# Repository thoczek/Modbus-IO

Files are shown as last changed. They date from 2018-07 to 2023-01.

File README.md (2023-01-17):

# Modbus-IO modules<br>

### Complete Modbus I/O modules on ATmega8<br>
### Contains:<br>
 - 4DI-4DO - 4 digital inputs 24VDC and 4 relay NO/NC outputs<br>
 - 8DI - 8 digital inputs 24VDC<br>
 - 7RO - 7 Relay outputs NO/NC<br>
 - WIFI - Module for WIFI conectibity for modules<br>
 - EAP-MODBUSconfig - Software for configuration of the modules.<br>
   Modules have possibility to act in TCP mode throught WIFi module.<br>

### Technology used:
Schematics and PCB board done in Kicad.<br>
Firmware - C++ eclipse. <br>
Software - C#

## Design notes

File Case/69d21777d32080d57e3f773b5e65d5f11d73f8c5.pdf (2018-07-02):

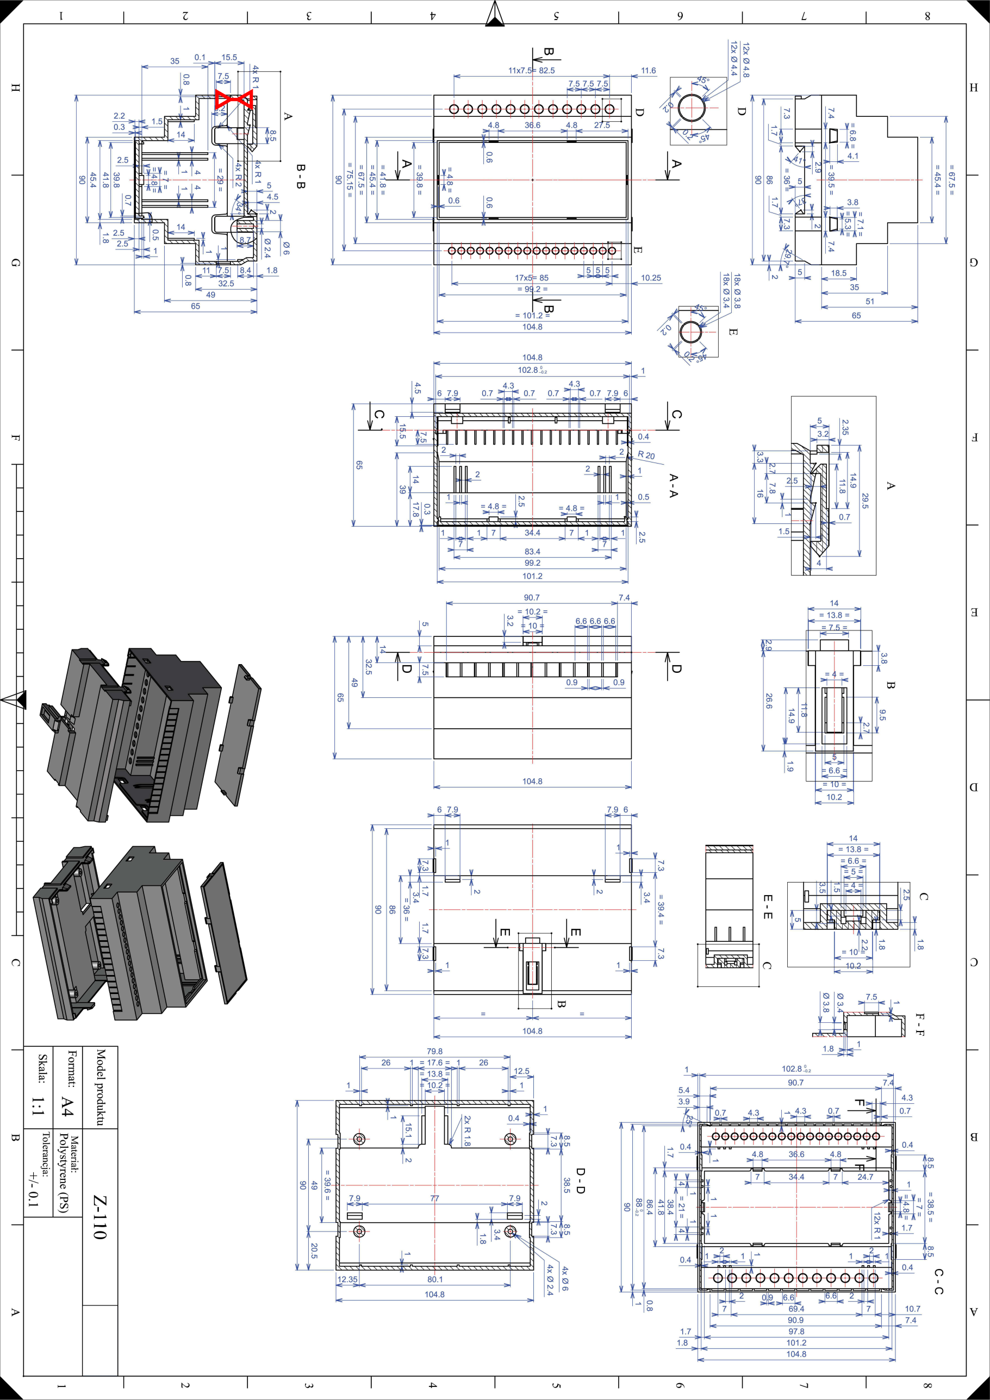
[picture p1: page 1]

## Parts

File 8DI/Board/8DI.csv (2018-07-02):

ref | value
C1 | 30pF
C2 | 30pF
C3 | 100nF
C4 | 47uF
C5 | 4,7uF
C6 | 47uF
C7 | 100nF
C8 | 100nF
C9 | 100nF
C10 | 100nF
C11 | 100nF
C12 | 100nF
C13 | 100nF
C14 | 100nF
C15 | 100nF
C16 | 4,7uF
C17 | 100nF
C18 | 100nF
C19 | 100nF
C20 | 100nF
D1 | DIODE
D2 | Tr 30V
D3 | LED
D4 | Tr 5.8V
D5 | Tr 5.8V
D6 | Tr 5.8V
D7 | Tr 5.8V
D8 | Tr 5.8V
D9 | Tr 5.8V
D10 | Tr 5.8V
D11 | Tr 5.8V
D12 | Tr 5.8V
D13 | Tr 5.8V
IC1 | ATMEGA8-P
IC2 | ADM485
P1 | 3 PIN
P2 | 5 PIN
P3 | 3 PIN
P8 | 5 PIN
R1 | 4.7k
R2 | 3k
R3 | 10k
R4 | 10k
R5 | 10k
R6 | 10k
R7 | 10k
R8 | 10k
R9 | 10k
R10 | 10k
R11 | 3k
R12 | 3k
R13 | 3k
R14 | 3k
R15 | 10R
R16 | 10R
R17 | 3k
R18 | 3k
R19 | 3k
R20 | 3k
U1 | 7805
U2 | LTV847
U3 | LTV847
X1 | 3.6864 MHz

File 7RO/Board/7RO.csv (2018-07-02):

ref | value
C1 | 30pF
C2 | 30pF
C3 | 100nF
C4 | 47uF
C5 | 4,7uF
C6 | 47uF
C7 | 100nF
C8 | 100nF
C9 | 100nF
C12 | 100nF
C16 | 4,7uF
D1 | DIODE
D2 | Tr 30V
D3 | LED
D4 | Tr 5.8V
D5 | Tr 5.8V
D6 | DIODE
D7 | DIODE
D8 | DIODE
D10 | DIODE
D11 | DIODE
D12 | DIODE
D13 | DIODE
IC1 | ATMEGA8-P
IC2 | ADM485
K1 | RELAY
K2 | RELAY
K3 | RELAY
K4 | RELAY
K5 | RELAY
K6 | RELAY
K7 | RELAY
P1 | 3 PIN
P2 | 3 PIN
P3 | 3 PIN
P4 | 3 PIN
P5 | 3 PIN
P6 | 3 PIN
P7 | 3 PIN
P8 | 3 PIN
P9 | 3 PIN
Q1 | BC337
Q2 | BC337
Q3 | BC337
Q4 | BC337
Q5 | BC337
Q6 | BC337
Q7 | BC337
R1 | 4.7k
R2 | 3k
R3 | 450
R4 | 450
R5 | 450
R7 | 450
R8 | 450
R9 | 450
R10 | 450
R15 | 10R
R16 | 10R
U1 | 7805
X1 | 3.6864 MHz

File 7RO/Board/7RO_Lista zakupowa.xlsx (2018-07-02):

Nazwa | Wartość | Napięcie | Obudowa | Opis
C1 | 27pF | 10V | Rozstaw 2,5mm | ceramiczny
C2 | 27pF | 10V | Rozstaw 2,5mm | ceramiczny
C3 | 100nF | 10V | Rozstaw 5mm | ceramiczny
C4 | 47uF | 35V | Rozstaw 2,5mm | elektrolityczny
C5 | 4,7uF | 35V | Rozstaw 2,5mm | elektrolityczny
C6 | 47uF | 35V | Rozstaw 2,5mm | elektrolityczny
C7 | 100nF | 10V | Rozstaw 5mm | ceramiczny
C8 | 100nF | 10V | Rozstaw 5mm | ceramiczny
C9 | 100nF | 10V | Rozstaw 5mm | ceramiczny
C12 | 100nF | 10V | Rozstaw 5mm | ceramiczny
C16 | 4,7uF | 35V | Rozstaw 2,5mm | elektrolityczny
D1 | DIODE | >35V | DO41 | dioda prostownicza 1A
D2 | Tr 30V | 30V | TO204 | Transil jednokierunkowy 30V 400 W
D3 | LED |  | 3mm | Zielona
D4 | Tr 5.8V | 5,8V | TO204 | Transil jednokierunkowy 5,8V 400 W
D5 | Tr 5.8V | 5,8V | TO204 | Transil jednokierunkowy 5,8V 400 W
D6 | DIODE | >35V | DO41 | dioda prostownicza 1A
D7 | DIODE | >35V | DO41 | dioda prostownicza 1A
D8 | DIODE | >35V | DO41 | dioda prostownicza 1A
D10 | DIODE | >35V | DO41 | dioda prostownicza 1A
D11 | DIODE | >35V | DO41 | dioda prostownicza 1A
D12 | DIODE | >35V | DO41 | dioda prostownicza 1A
D13 | DIODE | >35V | DO41 | dioda prostownicza 1A
IC1 | ATMEGA8-P |  | DIP28
IC2 | SP485 |  | DIP8
K1 | RELAY | 24 VDC | SRD-24VDC-SL-C | lub odpowiednik (nie wyższy niż 15,3mm)
K2 | RELAY | 24 VDC | SRD-24VDC-SL-C | lub odpowiednik (nie wyższy niż 15,3mm)
K3 | RELAY | 24 VDC | SRD-24VDC-SL-C | lub odpowiednik (nie wyższy niż 15,3mm)
K4 | RELAY | 24 VDC | SRD-24VDC-SL-C | lub odpowiednik (nie wyższy niż 15,3mm)
K5 | RELAY | 24 VDC | SRD-24VDC-SL-C | lub odpowiednik (nie wyższy niż 15,3mm)
K6 | RELAY | 24 VDC | SRD-24VDC-SL-C | lub odpowiednik (nie wyższy niż 15,3mm)
K7 | RELAY | 24 VDC | SRD-24VDC-SL-C | lub odpowiednik (nie wyższy niż 15,3mm)
P1 | 3 PIN |  |  | TBG-5-KB-3P-GN + TBW-5.08-K-3P
P2 | 3 PIN |  |  | TBG-5-KB-3P-GN + TBW-5.08-K-3P
P3 | 3 PIN |  |  | TBG-5-KB-3P-GN + TBW-5.08-K-3P
P4 | 3 PIN |  |  | TBG-5-KB-3P-GN + TBW-5.08-K-3P
P5 | 3 PIN |  |  | TBG-5-KB-3P-GN + TBW-5.08-K-3P
P6 | 3 PIN |  |  | TBG-5-KB-3P-GN + TBW-5.08-K-3P
P7 | 3 PIN |  |  | TBG-5-KB-3P-GN + TBW-5.08-K-3P
P8 | 3 PIN |  |  | TBG-5-KB-3P-GN + TBW-5.08-K-3P
P9 | 3 PIN |  |  | TBG-5-KB-3P-GN + TBW-5.08-K-3P
Q1 | BC337-16 |  | TO92
Q2 | BC337-16 |  | TO92
Q3 | BC337-16 |  | TO92
Q4 | BC337-16 |  | TO92
Q5 | BC337-16 |  | TO92
Q6 | BC337-16 |  | TO92
Q7 | BC337-16 |  | TO92
R1 | 4.7kΩ
R2 | 3,9kΩ
R3 | 560Ω
R4 | 560Ω
R5 | 560Ω
R7 | 560Ω
R8 | 560Ω
R9 | 560Ω
R10 | 560Ω
R15 | 10Ω
R16 | 10Ω
U1 | LM7805
X1 | 3.6864 MHz |  | Rezonator
xxx |  |  | DIP28 | Podstawka
xxx |  |  | DIP8 | Podstawka
XXX | ITALTRONIC |  | RAILBOX 22,5mm | Obudowa

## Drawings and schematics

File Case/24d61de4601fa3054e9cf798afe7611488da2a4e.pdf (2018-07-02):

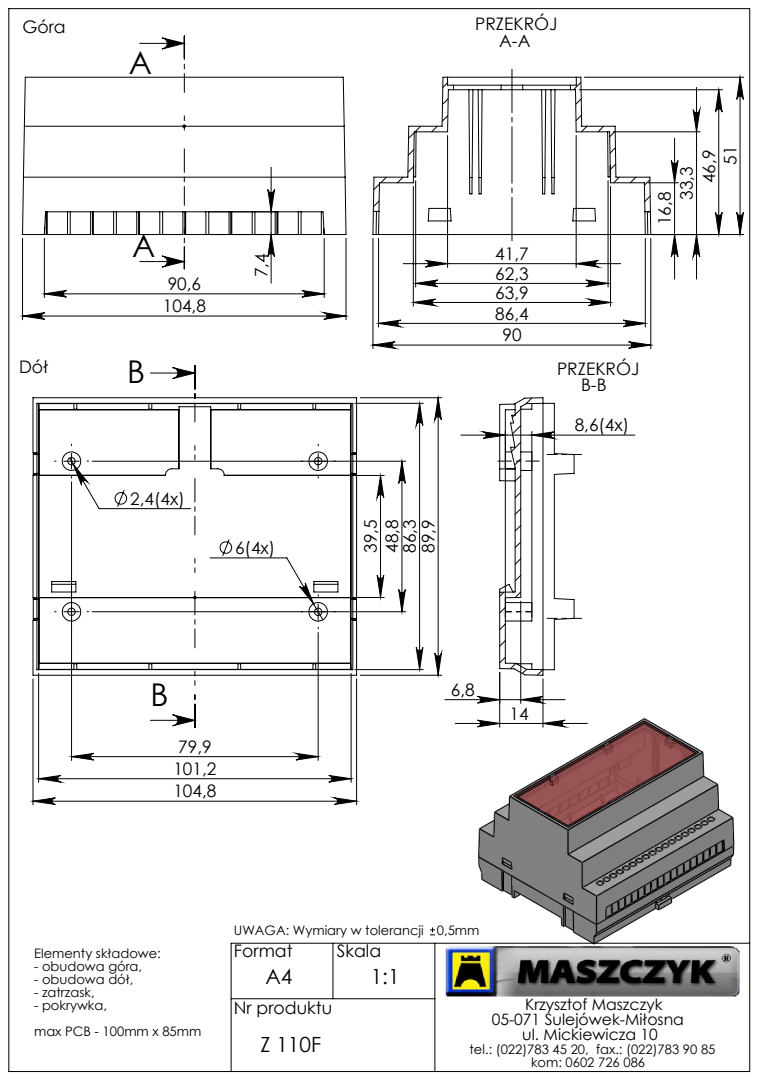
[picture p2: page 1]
kom: 0602 726 086; Elementy składowe: - obudowa góra, - obudowa dół, - zatrzask, - pokrywka, max PCB - 100mm x 85mm

UWAGA: Wymiary w tolerancji 0,5mm
Nr produktu

Krzysztof Maszczyk
05-071 Sulejówek-Miłosna ul. Mickiewicza 10
tel.: (022)783 45 20, fax.: (022)783 90 85

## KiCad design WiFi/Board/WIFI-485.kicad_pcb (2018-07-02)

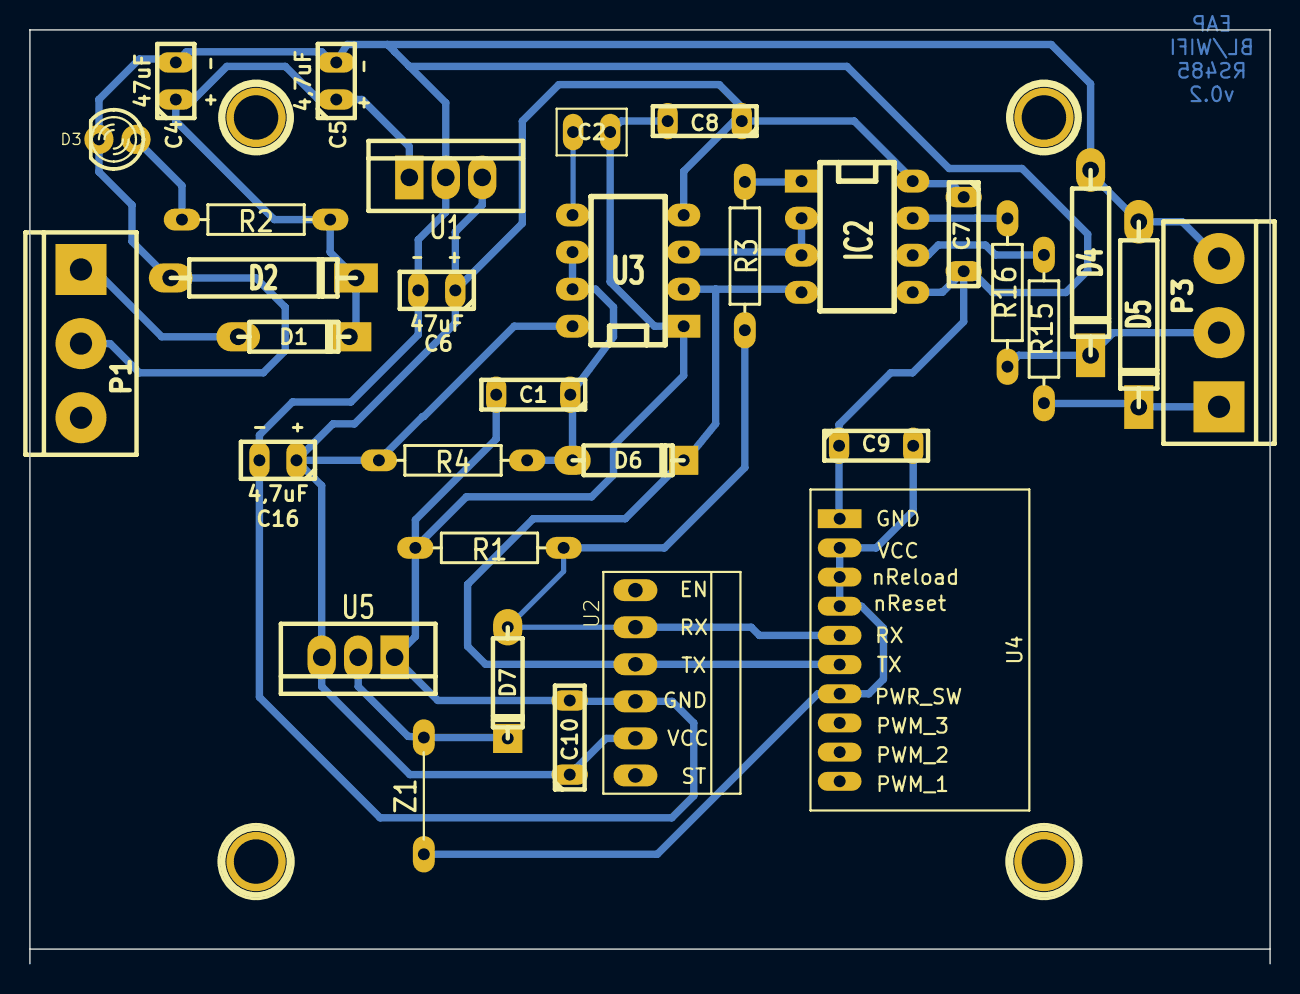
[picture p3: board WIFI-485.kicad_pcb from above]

Board: 2 copper layers, 85.0 x 64.0 mm, 32 parts (0 on the bottom side), 17 nets.

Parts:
C1: 220nF; C-5
C2: 10nF; C-2_5
C4, C6: 47uF; C-2_5
C5, C16: 4,7uF; C-2_5
C7, C8, C9, C10: 100nF; C-5
D1: DIODE; D3-BOLD
D2: Tr_30V; D5-BOLD
D3: LED; LED-3MM
D4, D5: Tr_15V; D5-BOLD
D6, D7: 1N4148; D3-BOLD
IC2: ADM485; DIP-8__300_ELL
P1, P3: 3_PIN; bornier3
R1: 2k; R-10
R2: 3,9k; R-10
R3: 1_k; R-10
R4: 10k; R-10
R15, R16: 10R; R-10
U1: 7805
U2: HC-05
U3: NE555; DIP-8__300_ELL
U4: USR-WIFI232-T
U5: LD1117V33_; LD1117V33
Z1: Z

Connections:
+5V: C6.1, C7.1, C8.1, C10.1, C16.1, IC2.8, R4.1, U1.VO, U2.2, U3.4, U3.8, U5.3
A: IC2.6, R15.2
B: IC2.7, R16.2
DGND: C1.2, C2.2, C4.2, C5.2, C6.2, C7.2, C8.2, C9.1, C10.2, C16.2, D2.1, D3.2, D4.1, D5.1, IC2.5, P1.2, P3.3, R1.1, U1.GND, U2.3, U3.1, U4.1, U5.1
unnamed: C2.1, U3.5
unnamed: IC2.1, R3.2
unnamed: D6.2, IC2.4, U2.4, U3.2, U4.6
unnamed: IC2.2, IC2.3, U3.3
unnamed: D7.1, R1.2, R3.1, U2.5, U4.5
unnamed: D7.2, U5.2, Z1.1
unnamed: C1.1, D6.1, R4.2, U3.6, U3.7
unnamed: C9.2, U4.2, U4.3, U4.4, U4.7, Z1.2
unnamed: D4.2, P3.2, R16.1
unnamed: D5.2, P3.1, R15.1
unnamed: D1.1, P1.1
unnamed: D3.1, R2.2
VCC: C4.1, C5.1, D1.2, D2.2, R2.1, U1.VI

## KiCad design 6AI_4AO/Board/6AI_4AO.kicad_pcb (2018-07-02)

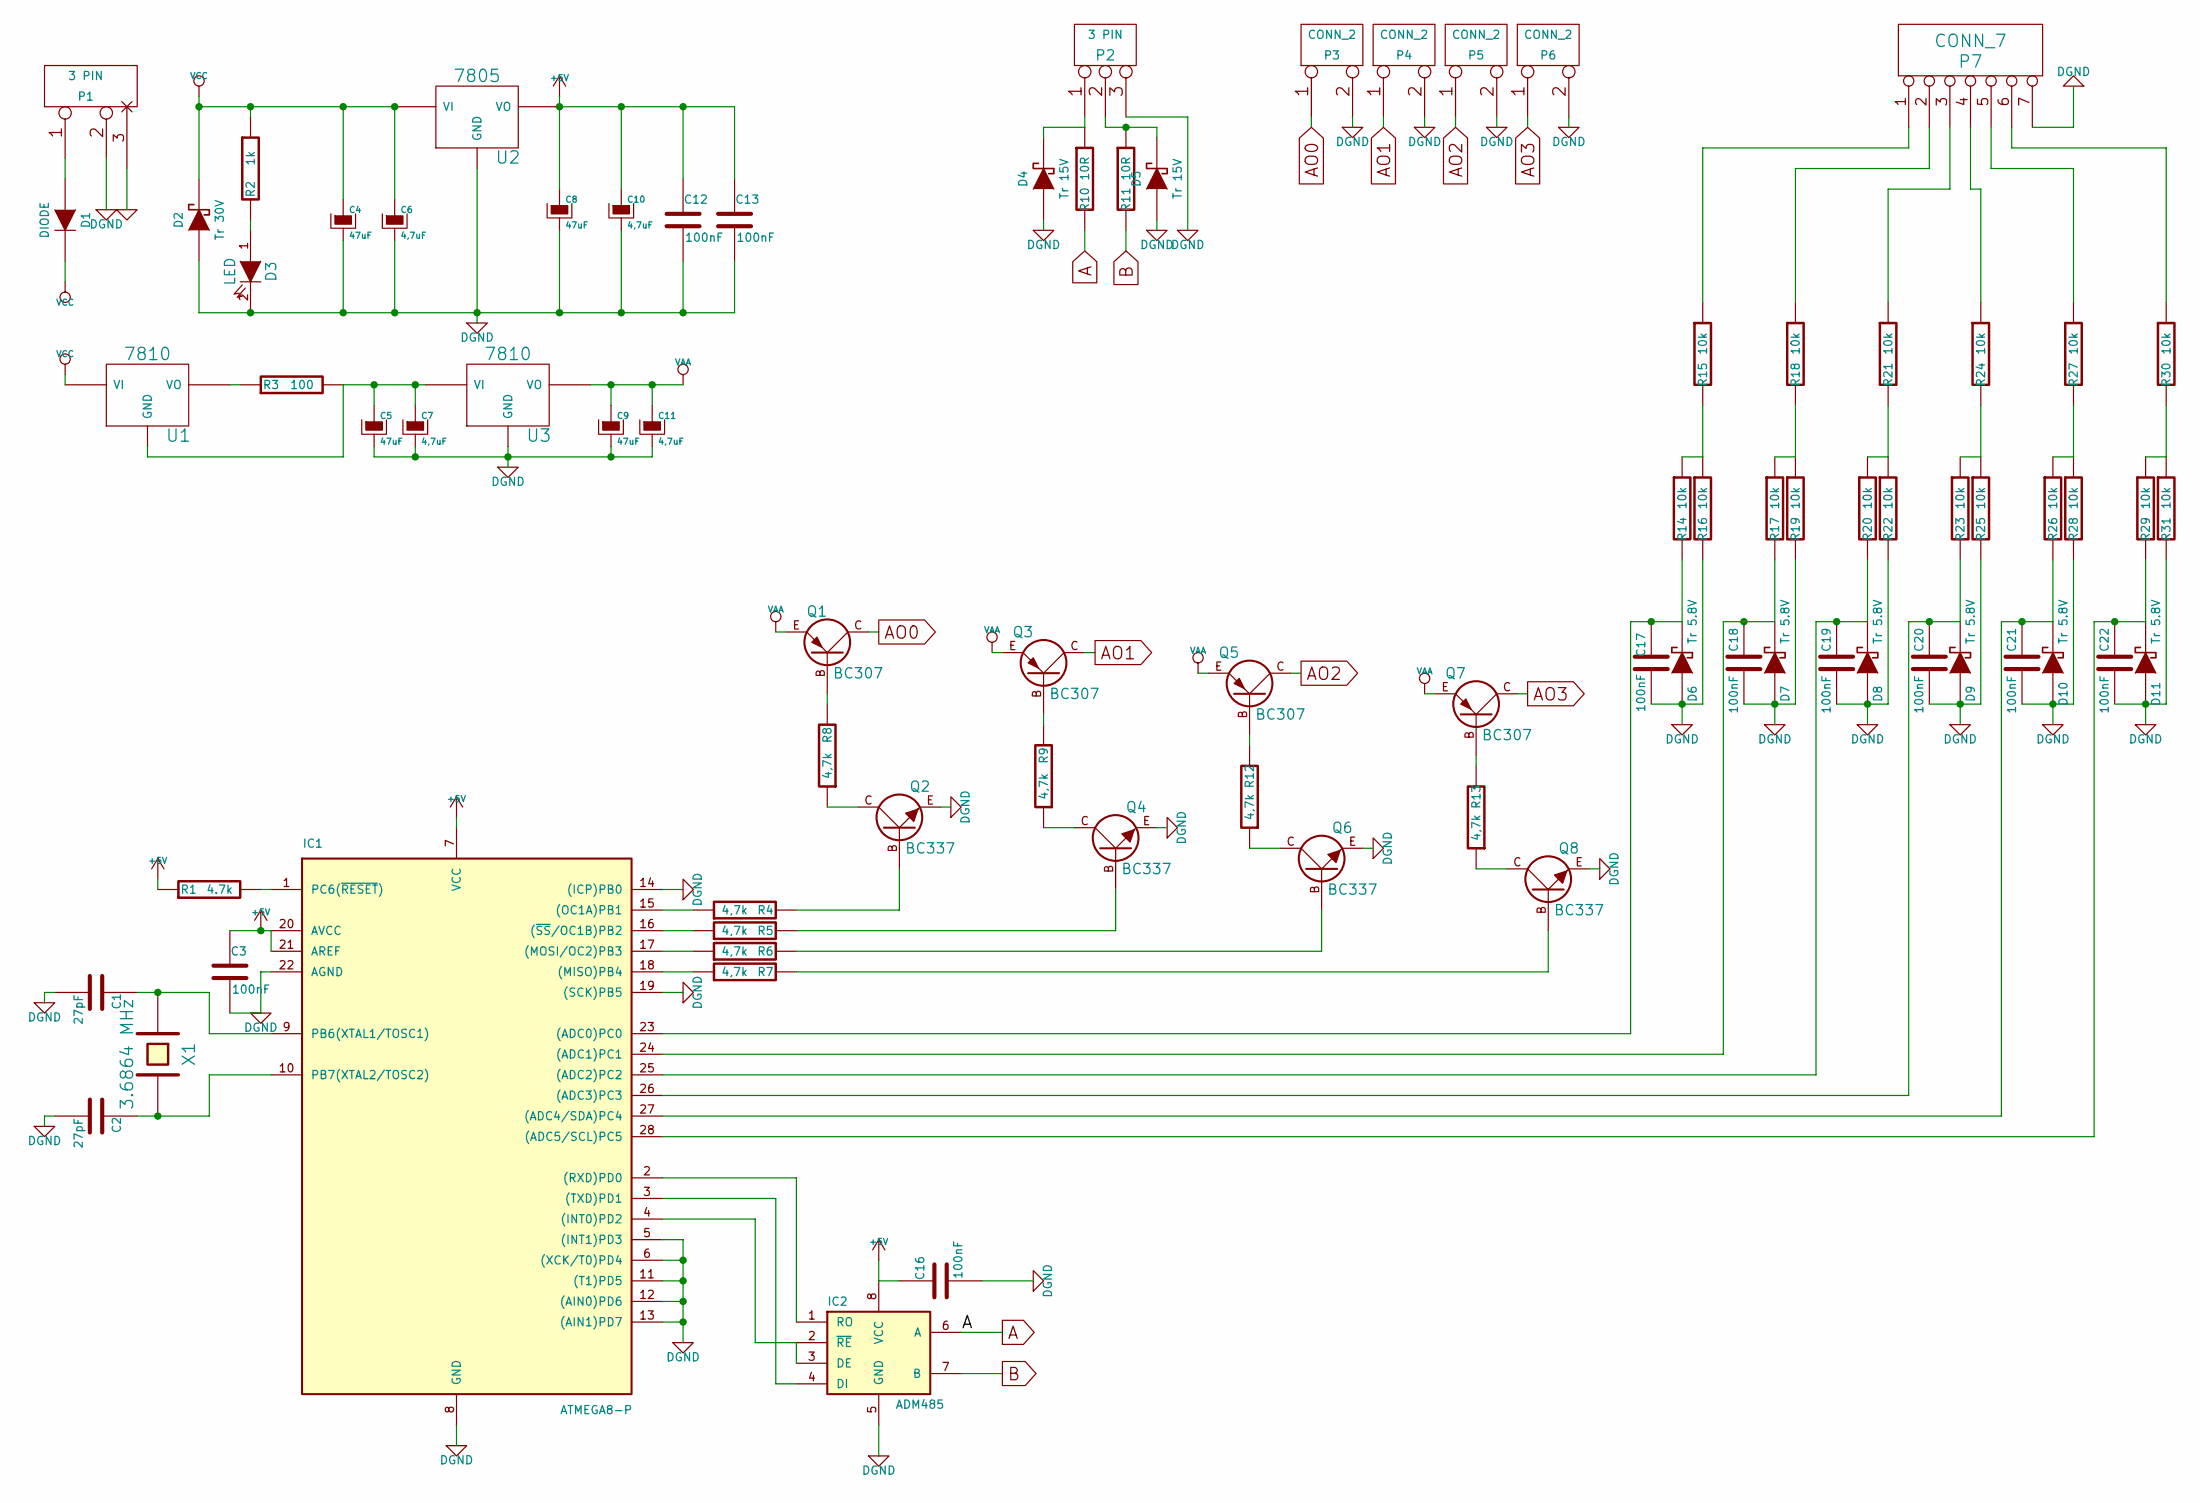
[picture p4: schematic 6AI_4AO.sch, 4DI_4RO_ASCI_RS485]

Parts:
C1, C2: 27pF; C-2_5
C3, C12, C13, C16, C17, C18, C19, C20, C21, C22: 100nF; C-5
C4, C5, C8, C9: 47uF; C-2_5
C6, C7, C10, C11: 4,7uF; C-2_5
D1: DIODE; D4-BOLD
D2: Tr 30V; D4-BOLD
D3: LED; LED-3MM
D4, D5: Tr 15V; D4-BOLD
D6, D7, D8, D9, D10, D11: Tr 5.8V; D4-BOLD
IC1: ATMEGA8-P; DIP-28_W7.62mm_LongPads
IC2: ADM485; DIP-8_W7.62mm_LongPads
P1, P2: 3 PIN; bornier3
P3, P4, P5, P6: CONN_2; bornier2
P7: CONN_7; bornier7
Q1, Q3, Q5, Q7: BC307; TO92_Moj
Q2, Q4, Q6, Q8: BC337; TO92_Moj
R1: 4.7k; R-7_62
R2: 1k; R-7_62
R3: 100; R-7_62
R4, R5, R6, R7, R8, R9, R12, R13: 4,7k; R-7_62
R10, R11: 10R; R-7_62
R14, R15, R16, R17, R18, R19, R20, R21, R22, R23, R24, R25, R26, R27, R28, R29, R30, R31: 10k; R-7_62
U1, U3: 7810; 7805
U2: 7805
X1: 3.6864 MHz; Osc_Moj

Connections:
+5V: C3.1, C8.1, C10.1, C12.1, C13.1, C16.1, IC1.7 (VCC), IC1.20 (AVCC), IC1.21 (AREF), IC2.8 (VCC), R1.1, U2.VO
A: IC2.6 (A), R10.2
AO0: P3.1, Q1.C
AO1: P4.1, Q3.C
AO2: P5.1, Q5.C
AO3: P6.1, Q7.C
B: IC2.7 (B), R11.2
DGND: C1.2, C2.2, C3.2, C4.2, C5.2, C6.2, C7.2, C8.2, C9.2, C10.2, C11.2, C12.2, C13.2, C16.2, C17.1, C18.2, C19.2, C20.2, C21.2, C22.2, D2.1 (A), D3.2 (K), D4.1 (A), D5.1 (A), D6.1 (A), D7.1 (A), D8.1 (A), D9.1 (A), D10.1 (A), D11.1 (A), IC1.5 ((INT1)PD3), IC1.6 ((XCK/T0)PD4), IC1.8 (GND), IC1.11 ((T1)PD5), IC1.12 ((AIN0)PD6), IC1.13 ((AIN1)PD7), IC1.14 ((ICP)PB0), IC1.19 ((SCK)PB5), IC1.22 (AGND), IC2.5 (GND), P1.2 (PM), P2.3, P3.2 (PM), P4.2 (PM), P5.2 (PM), P6.2 (PM), P7.7, Q2.E, Q4.E, Q6.E, Q8.E, R16.2, R19.2, R22.2, R25.2, R28.2, R31.2, U2.GND, U3.GND
GND: P1.3 (GND)
unnamed: C1.1, IC1.9 (PB6(XTAL1/TOSC1)), X1.1
unnamed: C2.1, IC1.10 (PB7(XTAL2/TOSC2)), X1.2
unnamed: C5.1, C7.1, R3.2, U1.GND, U3.VI
unnamed: C17.2, D6.2 (K), IC1.23 ((ADC0)PC0), R14.2
unnamed: C18.1, D7.2 (K), IC1.24 ((ADC1)PC1), R17.2
unnamed: C19.1, D8.2 (K), IC1.25 ((ADC2)PC2), R20.2
unnamed: C20.1, D9.2 (K), IC1.26 ((ADC3)PC3), R23.2
unnamed: C21.1, D10.2 (K), IC1.27 ((ADC4/SDA)PC4), R26.2
unnamed: C22.1, D11.2 (K), IC1.28 ((ADC5/SCL)PC5), R29.2
unnamed: D1.1 (A), P1.1
unnamed: D3.1 (A), R2.2
unnamed: D4.2 (K), P2.1, R10.1
unnamed: D5.2 (K), P2.2 (PM), R11.1
unnamed: IC1.1 (PC6(~RESET~)), R1.2
unnamed: IC1.2 ((RXD)PD0), IC2.1 (RO)
unnamed: IC1.3 ((TXD)PD1), IC2.4 (DI)
unnamed: IC1.4 ((INT0)PD2), IC2.2 (~RE~), IC2.3 (DE)
unnamed: IC1.15 ((OC1A)PB1), R4.1
unnamed: IC1.16 ((~SS~/OC1B)PB2), R5.1
unnamed: IC1.17 ((MOSI/OC2)PB3), R6.1
unnamed: IC1.18 ((MISO)PB4), R7.1
unnamed: P7.1, R15.1
unnamed: P7.2, R18.1
unnamed: P7.3, R21.1
unnamed: P7.4, R24.1
unnamed: P7.5, R27.1
unnamed: P7.6, R30.1
unnamed: Q1.B, R8.2
unnamed: Q2.B, R4.2
unnamed: Q2.C, R8.1
unnamed: Q3.B, R9.2
unnamed: Q4.B, R5.2
unnamed: Q4.C, R9.1
unnamed: Q5.B, R12.2
unnamed: Q6.B, R6.2
unnamed: Q6.C, R12.1
unnamed: Q7.B, R13.2
unnamed: Q8.B, R7.2
unnamed: Q8.C, R13.1
unnamed: R3.1, U1.VO
unnamed: R14.1, R15.2, R16.1
unnamed: R17.1, R18.2, R19.1
unnamed: R20.1, R21.2, R22.1
unnamed: R23.1, R24.2, R25.1
unnamed: R26.1, R27.2, R28.1
unnamed: R29.1, R30.2, R31.1
VAA: C9.1, C11.1, Q1.E, Q3.E, Q5.E, Q7.E, U3.VO
VCC: C4.1, C6.1, D1.2 (K), D2.2 (K), R2.1, U1.VI, U2.VI

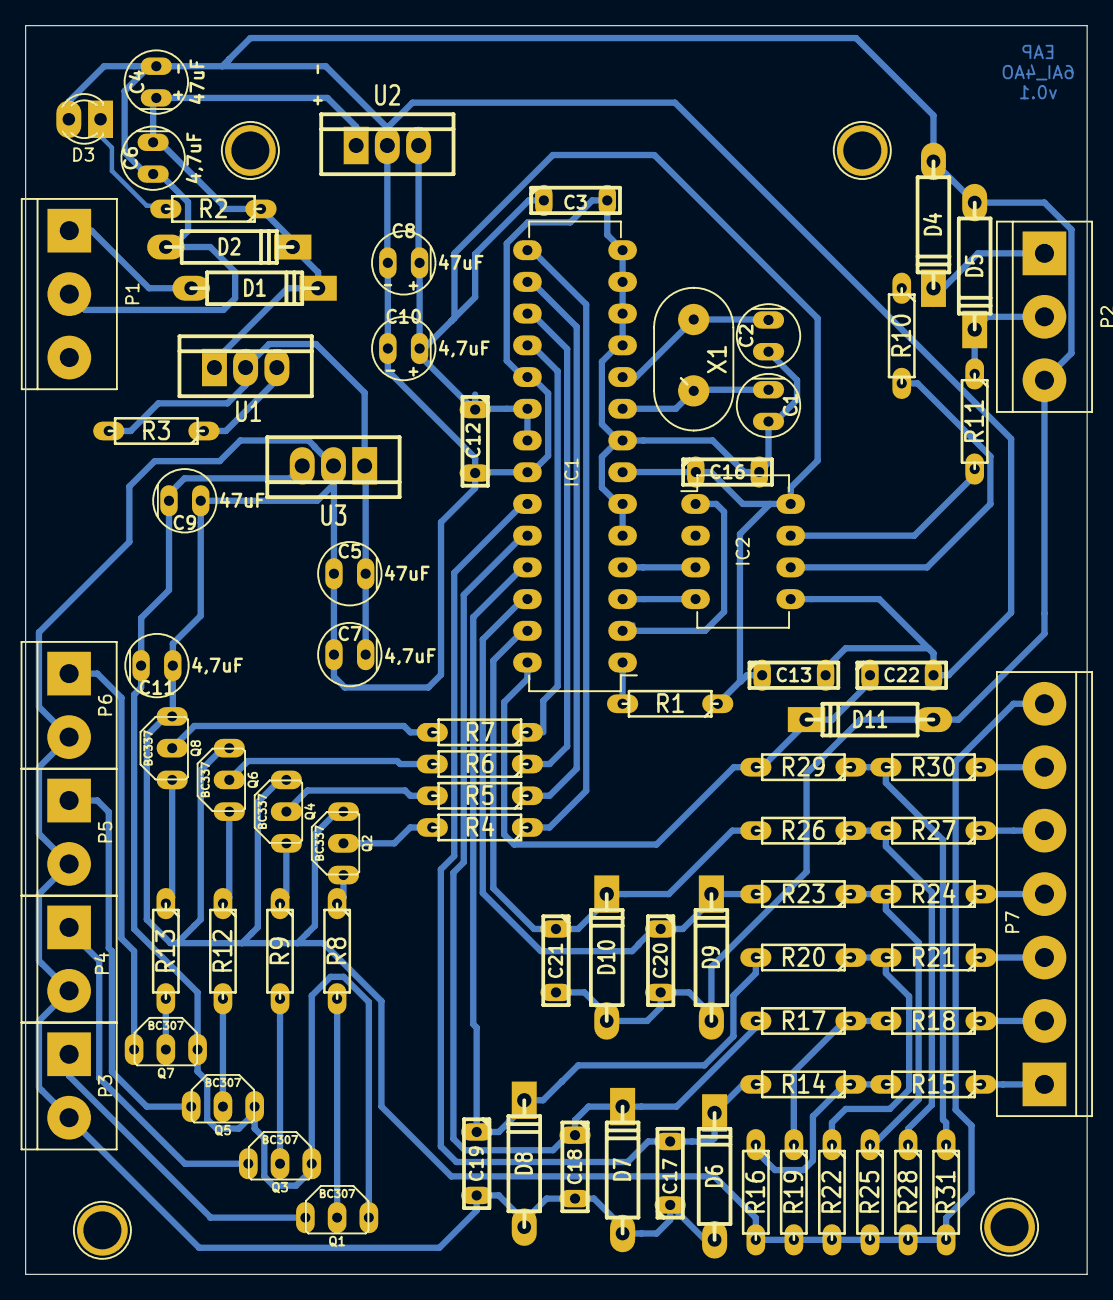
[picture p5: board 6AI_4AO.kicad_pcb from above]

Board: 2 copper layers, 85.0 x 100.0 mm, 83 parts (0 on the bottom side), 56 nets.

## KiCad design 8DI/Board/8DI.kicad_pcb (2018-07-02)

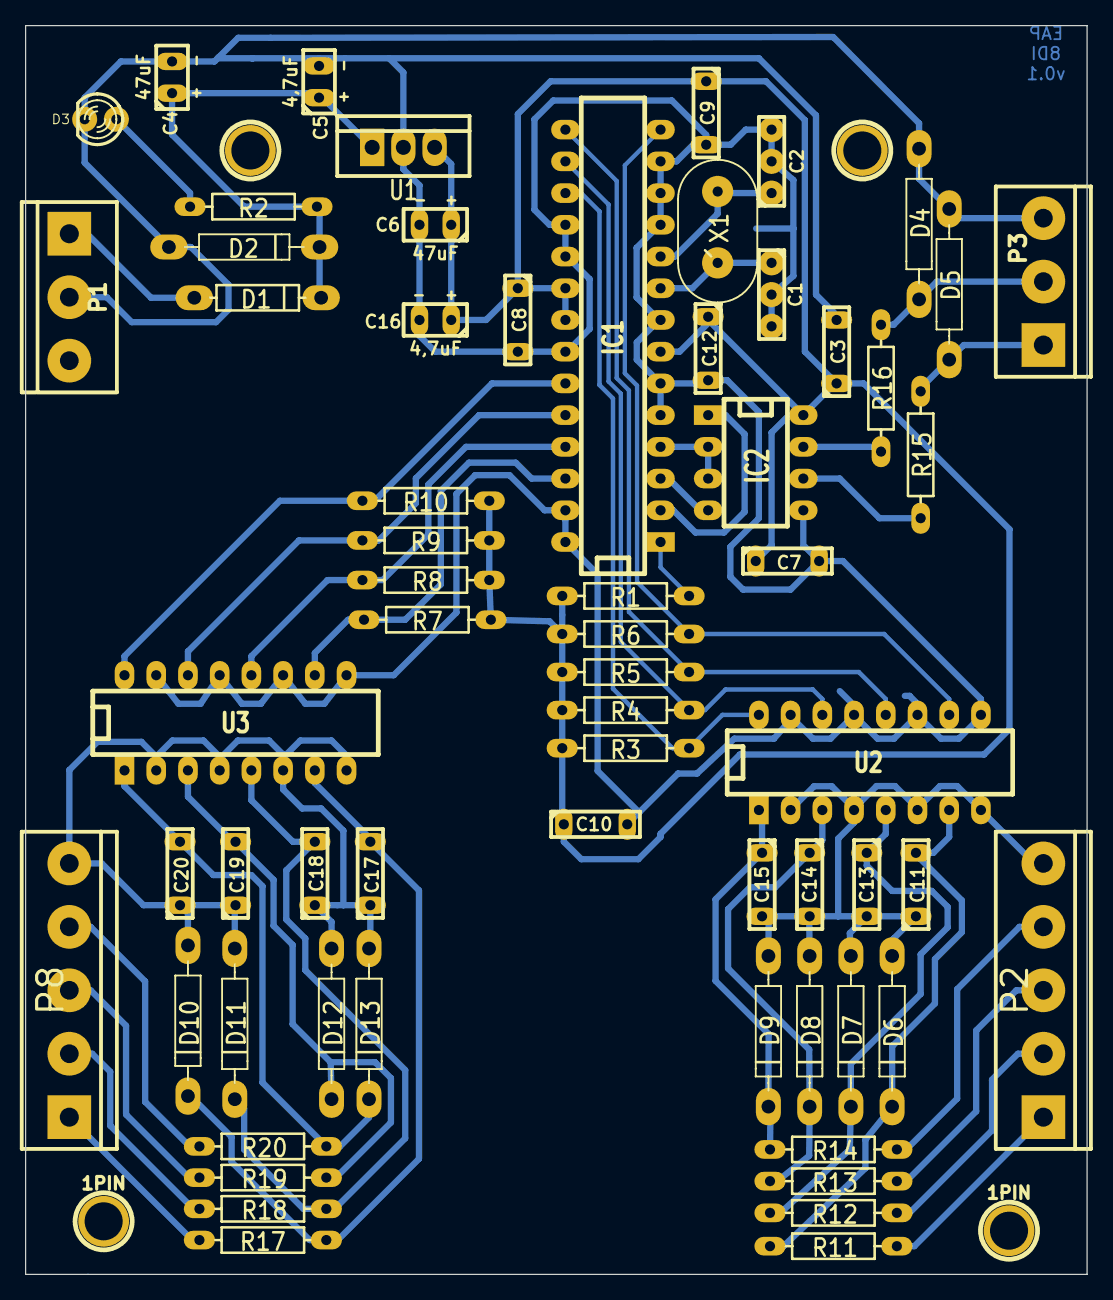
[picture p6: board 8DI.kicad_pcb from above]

Board: 2 copper layers, 85.0 x 100.0 mm, 65 parts (0 on the bottom side), 40 nets.

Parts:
1PIN, 1PIN#2: P***; 1pin
C1, C2: C; C1-1
C3, C7, C8, C9, C10, C11, C12, C13, C14, C15, C17, C18, C19, C20: 100nF; C-5
C4, C6: 47uF; C-2_5
C5, C16: 4,7uF; C-2_5
D1: R-10
D2, D4, D5, D6, D7, D8, D9, D10, D11, D12, D13: R-12
D3: LED-3MM
IC1: ATMEGA8-P; DIP-28__300_ELL
IC2: DIP-8__300_ELL
P1, P3: bornier3
P2, P8: bornier5
R1, R2, R3, R4, R5, R6, R7, R8, R9, R10, R11, R12, R13, R14, R15, R16, R17, R18, R19, R20: R-10
U1: 7805
U2, U3: DIP-16__300_ELL
X1: Osc_Moj

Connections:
+5V: C3.1, C6.1, C7.1, C8.1, C9.1, C10.1, C12.1, C16.1, IC1.7, IC1.20, IC1.21, IC2.8, R1.1, R3.1, R4.1, R5.1, R6.1, R7.2, R8.2, R9.2, R10.2, U1.VO
A: IC2.6, R15.2
B: IC2.7, R16.2
DGND: C1.2, C2.2, C3.2, C4.2, C5.2, C6.2, C7.2, C8.2, C9.2, C10.2, C12.2, C16.2, D2.1, D3.2, D4.1, D5.1, IC1.5, IC1.6, IC1.8, IC1.11, IC1.12, IC1.13, IC1.18, IC1.19, IC1.22, IC1.27, IC1.28, IC2.5, P1.2, P3.3, U1.GND, U2.9, U2.11, U2.13, U2.15, U3.9, U3.11, U3.13, U3.15
GNDPWR: C11.1, C13.2, C14.2, C15.2, C17.1, C18.1, C19.1, C20.1, D6.1, D7.1, D8.1, D9.1, D10.1, D11.1, D12.1, D13.1, P2.5, P8.5, U2.2, U2.4, U2.6, U2.8, U3.2, U3.4, U3.6, U3.8
unnamed: P2.2, R12.1
unnamed: D5.2, P3.1, R15.1
unnamed: IC1.4, IC2.2, IC2.3
unnamed: D1.1, P1.1
unnamed: D3.1, R2.2
unnamed: P2.1, R11.1
unnamed: IC1.2, IC2.1
unnamed: IC1.3, IC2.4
unnamed: P2.3, R13.1
unnamed: P2.4, R14.1
unnamed: P8.2, R18.2
unnamed: P8.3, R19.2
unnamed: P8.4, R20.2
unnamed: IC1.24, R9.1, U3.14
unnamed: C20.2, D13.2, R20.1, U3.1
unnamed: IC1.25, R8.1, U3.12
unnamed: P8.1, R17.2
unnamed: C17.2, D10.2, R17.1, U3.7
unnamed: C18.2, D11.2, R18.1, U3.5
unnamed: C19.2, D12.2, R19.1, U3.3
unnamed: IC1.26, R7.1, U3.10
unnamed: C14.1, D8.2, R13.2, U2.3
unnamed: C15.1, D9.2, R14.2, U2.1
unnamed: C1.1, IC1.9, X1.1
unnamed: C2.1, IC1.10, X1.2
unnamed: C11.2, D6.2, R11.2, U2.7
unnamed: C13.1, D7.2, R12.2, U2.5
unnamed: IC1.23, R10.1, U3.16
unnamed: IC1.1, R1.2
unnamed: IC1.17, R3.2, U2.16
unnamed: IC1.14, R6.2, U2.10
unnamed: IC1.15, R5.2, U2.12
unnamed: IC1.16, R4.2, U2.14
unnamed: D4.2, P3.2, R16.1
VCC: C4.1, C5.1, D1.2, D2.2, R2.1, U1.VI

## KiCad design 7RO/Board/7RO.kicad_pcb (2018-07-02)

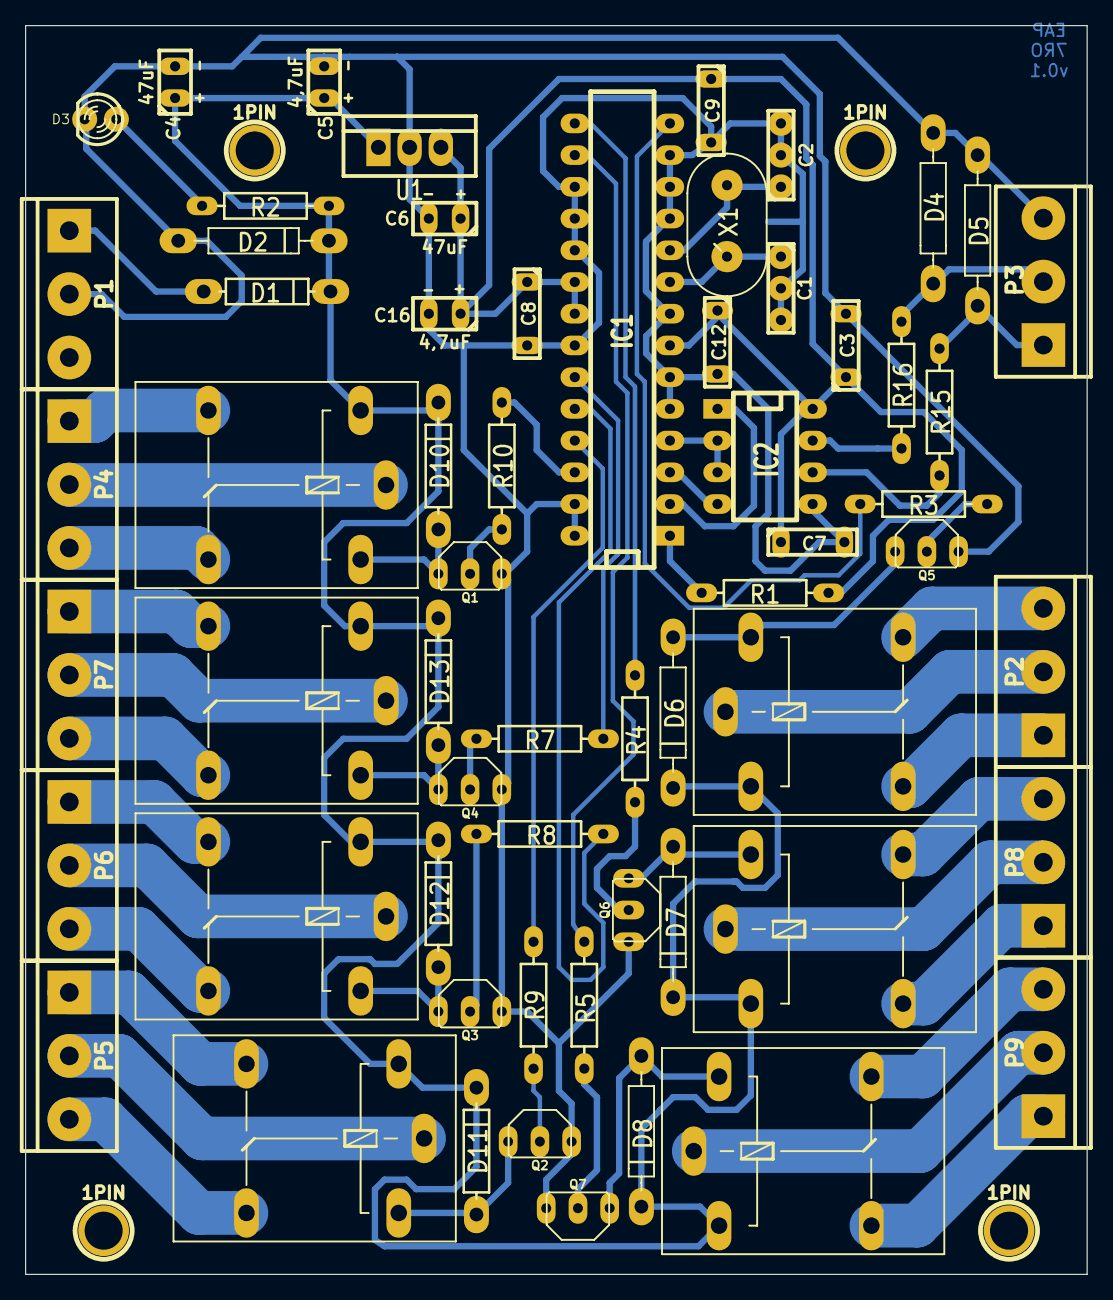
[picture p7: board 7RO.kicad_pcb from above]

Board: 2 copper layers, 85.0 x 100.0 mm, 65 parts (0 on the bottom side), 57 nets.

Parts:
1PIN, 1PIN#2, 1PIN#3, 1PIN#4: P***; 1pin
C1, C2: C; C1-1
C3, C7, C8, C9, C12: 100nF; C-5
C4, C6: 47uF; C-2_5
C5, C16: 4,7uF; C-2_5
D1: R-10
D2, D4, D5, D6, D7, D8: R-12
D3: LED; LED-3MM
D10, D11, D12, D13: DIODE; R-10
IC1: ATMEGA8-P; DIP-28__300_ELL
IC2: DIP-8__300_ELL
K1, K2, K3, K4, K5, K6, K7: relay-G5LE
P1: CONN_PWR; bornier3
P2, P3, P4, P5, P6, P7, P8, P9: bornier3
Q1, Q2, Q3, Q4, Q5, Q6, Q7: BC337; TO92_Moj
R1: 4.7k; R-10
R2: 3k; R-10
R3, R4, R5, R15, R16: R-10
R7, R8, R9, R10: 450; R-10
U1: 7805
X1: CRYSTAL; Osc_Moj

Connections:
+5V: C3.1, C6.1, C7.1, C8.1, C9.1, C12.1, C16.1, IC1.7, IC1.20, IC1.21, IC2.8, R1.1, U1.VO
A: IC2.6, R15.2
B: IC2.7, R16.2
DGND: C1.2, C2.2, C3.2, C4.2, C5.2, C6.2, C7.2, C8.2, C9.2, C12.2, C16.2, D2.1, D3.2, D4.1, D5.1, IC1.5, IC1.6, IC1.8, IC1.11, IC1.12, IC1.13, IC1.17, IC1.18, IC1.19, IC1.22, IC1.27, IC1.28, IC2.5, P1.2, P3.3, Q1.E, Q2.E, Q3.E, Q4.E, Q5.E, Q6.E, Q7.E, U1.GND
unnamed: K2.P, P5.2
unnamed: K1.O, P4.3
unnamed: K1.S, P4.1
unnamed: K1.P, P4.2
unnamed: K2.S, P5.1
unnamed: D10.1, K1.2, Q1.C
unnamed: K4.P, P7.2
unnamed: D5.2, P3.1, R15.1
unnamed: K4.S, P7.1
unnamed: K4.O, P7.3
unnamed: K3.S, P6.1
unnamed: K3.O, P6.3
unnamed: K3.P, P6.2
unnamed: K2.O, P5.3
unnamed: D3.1, R2.2
unnamed: D1.1, P1.1
unnamed: IC1.4, IC2.2, IC2.3
unnamed: IC1.3, IC2.4
unnamed: IC1.2, IC2.1
unnamed: D11.1, K2.2, Q2.C
unnamed: D12.1, K3.2, Q3.C
unnamed: D13.1, K4.2, Q4.C
unnamed: K7.P, P9.2
unnamed: Q5.B, R3.1
unnamed: Q7.B, R5.1
unnamed: Q6.B, R4.1
unnamed: K6.S, P8.1
unnamed: K7.S, P9.1
unnamed: K7.O, P9.3
unnamed: K6.O, P8.3
unnamed: K5.O, P2.3
unnamed: K5.S, P2.1
unnamed: K6.P, P8.2
unnamed: K5.P, P2.2
unnamed: IC1.16, R5.2
unnamed: IC1.15, R4.2
unnamed: IC1.14, R3.2
unnamed: D8.1, K7.2, Q7.C
unnamed: D7.1, K6.2, Q6.C
unnamed: D6.1, K5.2, Q5.C
unnamed: Q1.B, R10.1
unnamed: Q3.B, R8.1
unnamed: Q2.B, R9.1
unnamed: Q4.B, R7.1
unnamed: IC1.26, R10.2
unnamed: IC1.25, R9.2
unnamed: IC1.24, R8.2
unnamed: IC1.23, R7.2
unnamed: C2.1, IC1.10, X1.2
unnamed: C1.1, IC1.9, X1.1
unnamed: IC1.1, R1.2
unnamed: D4.2, P3.2, R16.1
VCC: C4.1, C5.1, D1.2, D2.2, D6.2, D7.2, D8.2, D10.2, D11.2, D12.2, D13.2, K1.1, K2.1, K3.1, K4.1, K5.1, K6.1, K7.1, R2.1, U1.VI
